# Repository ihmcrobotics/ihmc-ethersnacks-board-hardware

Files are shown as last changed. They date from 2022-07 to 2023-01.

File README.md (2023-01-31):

This repository replicates our internal Circuit Board Design Files repository, but only displays a portion of the material and documentation we intend to make public.
This project is  is licensed under the BSD 3-Clause "New" or "Revised" License.

EtherSNACKS - EtherCAT slave using Texas Instrument F28388 Processor
===
# Overview
EtherSNACKS board is an etherCAT slave based on the F28388D C2000 Real-time microcontroller. It allows any sensors or actuators to be interfaced on EtherCAT using GPIO, ADC, I2C, SPI, UART, CAN...

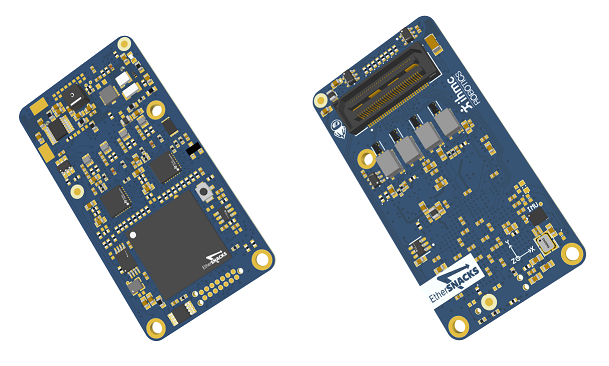
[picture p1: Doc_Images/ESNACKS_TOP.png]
EtherSNACKS Rev 1.2 PCB Top

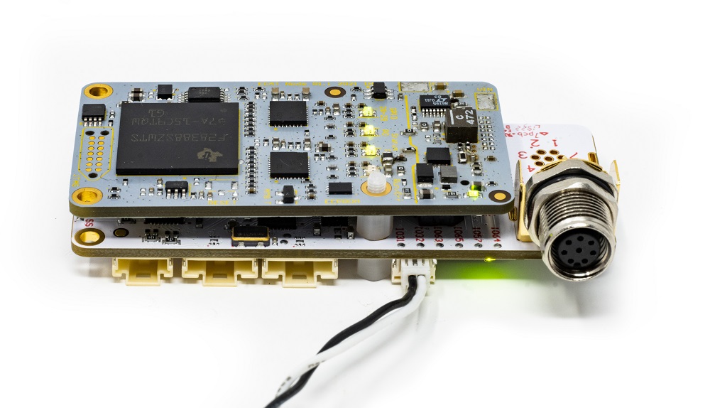
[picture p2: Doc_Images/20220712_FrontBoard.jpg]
EtherSNACKS on a daughter board


### Hardware release (production files)
* Rev 1.0 Initial version 

* Rev 1.1 Released version to fab with 8 layers stackup

* Rev 1.2 Change resistor R77 ADC REF to 100R instead of 1K 
		  Reverse voltage protection diode added

### Features
* TMS320F28388D 200 MHz dual C28xCPUs and dual CLAs, Connectivity Manager (CM) based on the ARM Cortex-M4 processor 125Mhz
* EtherCAT build-in and CAN-FD communication ports(CAN needs an external transceiver)
* IMU 6-axes TDK ICM-42688-P High-Precision with 32,768KHz external clock
* Ambient temperature sensor
* Voltage supervisors (3V3 and 1V2 CPU)
* ADC reference 3V ±0.05%
* 2 programmable LEDs
* Reset button
* JTAG 14-pin Plug-of-Nails (TC2070-IDC-NL)
* Boad-to-board 60 pins connector:
	* 2-port EtherCAT
	* 1-port CAN-FD
	* 2x I2C
	* 8x PWM (4*2 complementary PWM)
	* 3x SPI
	* 8x ADC
	* 2x SCI (UART)
	* up to 39 GPIOs (depending on the config)

### Electrical specifications
* Wide input voltage range: 8V to 60V
* Onboard buck 5V 1.2A
* Onboard buck 3V3 800mA

### Mechanical dimensions
* 58mm x 30.5mm (2.28" X 1.2")
* Height≈7.75mm

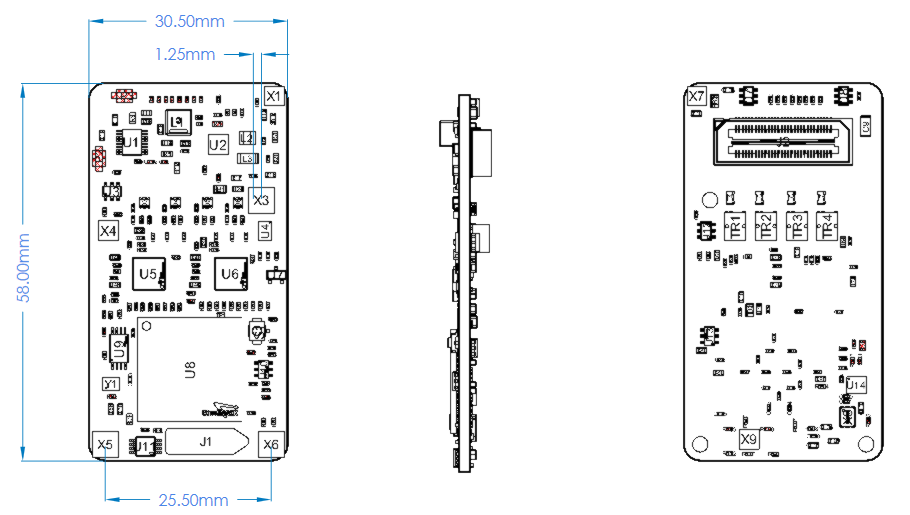
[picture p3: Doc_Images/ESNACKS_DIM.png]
EtherSNACKS Rev 1.2 Dimensions


### Files
Each board has its own folder containing the source files (schematic and layout on Altium), output files (gerber, BOM and pick and place for manufacturing), documents (schematic and layout in PDF files), images, configuration files for etherCAT etc.

### Examples
Onboard TDK ICM-42688P IMU on EtherCAT (TwinCAT):

Onboard TDK ICM-42688P IMU

STIM318 IMU interfaced with EtherSNACKS:

STIM318 IMU interfaced with EtherSNACKS

EtherSNACKS Testbed for development:

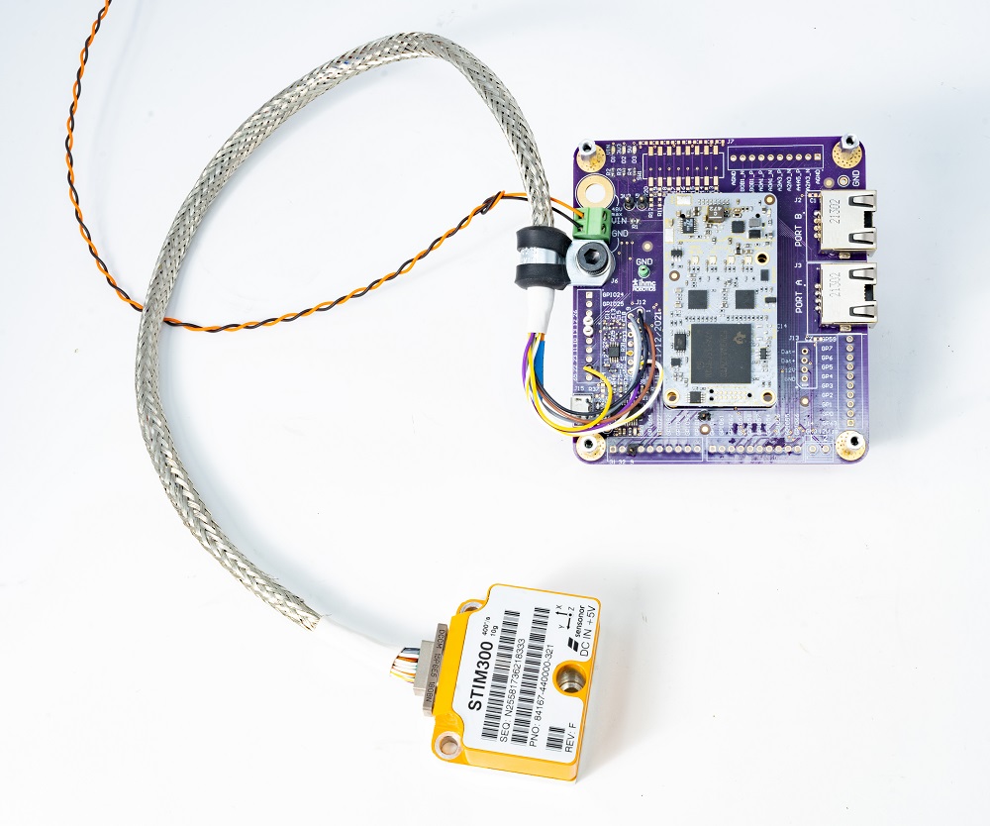
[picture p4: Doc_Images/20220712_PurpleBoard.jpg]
EtherSNACKS Testbed


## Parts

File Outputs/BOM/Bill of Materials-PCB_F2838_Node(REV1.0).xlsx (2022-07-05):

Designator | MPN | Quantity | Description | Footprint | Value
C1, C2, C3, C4, C5, C6, C7, C8 | CC0402JRNPO9BN331 | 8 | 0402 330 pF 50 V ±5 % Tolerance NP0 SMT Multilayer Ceramic Capacitor | 0402_C | 330p
C9 | C3216X7S2A225K160AB | 1 | CAP CER 2.2UF 100V X7S 1206 | CAPC3216X16N(1206) | 2.2uF
C10 | 885012005043 | 1 | Cap, Mlcc, Np0, 33Pf, 25V, 0402 Rohs Compliant: Yes | 0402_C | 33pF
C11, C13, C19, C21, C95, C106 | C1608X5R1A226M080AC | 6 | CAP CER 22UF 10V X5R 0603 | CAPC1608X09N(0603) | 22uF
C12, C14, C17 | CL10B104KC8NNNC | 3 | CAP CER 0.1UF 100V X7R 0603 | CAPC1608X09N(0603) | 0.1uF
C15, C20, C23, C25, C26, C27, C28, C29, C30, C31, C32, C33, C38, C39, C40, C43, C44, C47, C49, C50, C52, C56, C57, C58, C61, C65, C66, C67, C74, C75, C77, C78, C79, C80, C82, C83, C84, C85, C86, C87, C88, C90, C91, C92, C93, C94, C96, C97, C98, C99, C100, C103, C104, C105, C110 | GRM155R71C104JA88D | 55 | CAP CER 0.1UF 16V X7R 0402 | CAPC1005X03N(0402) | 100nF
C16, C18, C36, C37, C42, C46, C54, C55, C59, C60, C64, C73, C109 | C0603C105K3PACTU | 13 | MLCC - SMD/SMT 25volts 1uF X5R 10% | CAPC1608X09N(0603) | 1uF
C24, C89, C102, C107, C108, C111 | GRM188R61A225KE34D | 6 | CAP CER 2.2UF 10V X5R 0603 | CAPC1608X09N(0603) | 2.2uF
C34, C35 | C1005NP01H102J050BA | 2 | CAP CER 1000PF 50V NP0 0402 | 0402_C | 1nF
C41, C45, C63, C68, C72, C76 | CL10X106MO8NRNC | 6 | CAP CER 10UF 16V X6S 0603 | CAPC1608X09N(0603) | 10uF
C48 | GCM1555C1H471JA16D | 1 | CAP CER 470PF 50V C0G/NP0 0402 | CAPC1005X03N(0402) | 470pF
C51, C53, C62, C69, C70, C71, C101 | CC0402KRX7R9BB103 | 7 | CAP CER 10000PF 50V X7R 0402 | CAPC1005X03N(0402) | 10nF
C81 | CL10B104KB8NNNL | 1 | CAP CER 0.1UF 50V X7R 0603 | CAPC1608X09N(0603) | 100nF
D1 | LTST-C193KGKT-5A | 1 | LED GREEN CLEAR CHIP SMD | LEDC1608X07N(0603)
D2 | CFSH05-20L TR | 1 | Silicon SCHOTTKY Diode Low Forward Voltage 20V 3A 2-Pin SOD-882L Surface Mount T/R | SOD-882
D3, D6 | LTST-C195KGJRKT | 2 | LED GREEN/RED CLEAR CHIP SMD | Dual_LED
D4, D5 | LTST-C195KGJSKT | 2 | LED GREEN/YELLOW CLEAR CHIP SMD | Dual_LED
D7, D8 | TPD4E001QDBVRQ1 | 2 | TVS DIODE 5.5V 16V SOT23-6 | FP-DBV0006A-IPC_C
FB1, FB2, FB3 | BKP2125HS600-T | 3 | TAIYO YUDEN - BKP2125HS600-T - Ferrite Bead, 0805 [2012 Metric], 60 ohm, 3 A, BKP Series, 0.025 ohm, ± 25% | FP-BKP2125-IPC_C
J2 | QSH-030-01-F-D-A-K-TR | 1 | Conn Micro High Speed Socket Strip SKT 60 POS 0.5mm Solder ST SMD Automotive T/R | FP-QSH-030-01-F-D-A-K-TR-MFG
L1 | XGL4030-472MEC | 1 | Inductor Power Shielded Wirewound 4.7uH 20% 1MHz Composite 6.6A 31.5mOhm DCR Automotive T/R | FP-XGL4030-472MEC-MFG | 4u7
L2 | 74438323033 | 1 | Inductor Power Shielded Wirewound 3.3uH 20% 100KHz Powdered Iron 1.25A 264mOhm DCR 1008 T/R | SMD 2510 | 3u3
L3 | PFL3215-222MEB | 1 | Power inductor, shielded, 20% tol, SMT, RoHS, halogen-f | 1206_L | 2u2
L4, L5, L6, L7 | DLW21HN900SQ2L | 4 | MURATA - DLW21HN900SQ2L - Filter, Common Mode, 90 ohm, 0.33 A, DLW21H Series, 2 mm x 1.2 mm x 0.9 mm | FP-DLW21HN-MFG
R1 | ERJ-2RKF2003X | 1 | Res Thick Film 0402 200K Ohm 1% 1/10W ±100ppm/|C SMD Punched Carrier T/R | 0402 | 200k
R2 | CRCW0402205KFKED | 1 | Res Thick Film 0402 205K Ohm 1% 1/16W ±100ppm/°C Molded SMD SMD Paper T/R | 0402 | 205k
R3 | RC0603FR-071ML | 1 | RES SMD 1M OHM 1% 1/10W 0603 | RESC1608X09N(0603) | 1M
R4 | CRCW040222K0JNED | 1 | Res Thick Film 0402 22K Ohm 5% 1/16W ±200ppm/°C Molded SMD SMD Paper T/R | 0402 | 22k
R5 | ERJ-3EKF1003V | 1 | Res Thick Film 0603 100K Ohm 1% 0.1W(1/10W) ±100ppm/C Pad SMD Automotive T/R | RESC1608X09N(0603) | 100k
R6, R37, R38, R78, R99, R109, R110 | RC0402FR-0710KL | 7 | RES SMD 10K OHM 1% 1/16W 0402 | RESC1005X06N(0402) | 10k
R7 | RC0603FR-07680RL | 1 | RES SMD 680 OHM 1% 1/10W 0603 | RESC1608X09N(0603) | 680R
R8, R12, R17 | RC0603JR-070RL | 3 | RES SMD 0 OHM JUMPER 1/10W 0603 | RESC1608X09N(0603) | 0R
R9 | CRCW0402340KFKED | 1 | Res Thick Film 0402 340K Ohm 1% 1/16W ±100ppm/°C Molded SMD SMD Paper T/R | 0402 | 340k
R10 | ERJ-2RKF2002X | 1 | RES SMD 20K OHM 1% 1/10W 0402 | 0402 | 20k
R13, R43, R44, R45, R47, R71, R75, R76, R81, R82, R83, R84, R85, R86, R87, R88, R102, R103, R105, R111 | RCS04020000Z0ED | 20 | VISHAY - RCS04020000Z0ED - SMD Chip Resistor, 0402 [1005 Metric], 0 ohm, RCS Series, 50 V, Thick Film, 200 mW | 0402 | 0R
R14, R18, R89, R90 | CRCW04021M50JNED | 4 | RES SMD 1.5M OHM 5% 1/16W 0402 | 0402 | 1M5
R15 | RT0603DRE0775KL | 1 | Res Thin Film 0603 75K Ohm 0.5% 1/10W ±50ppm/°C Molded SMD SMD Paper T/R | 0603 | 75k
R16 | RC0402FR-072KL | 1 | RES SMD 2K OHM 1% 1/16W 0402 | RESC1005X06N(0402) | 2k
R19, R20, R21, R22, R23, R24, R25, R26 | CRCW0402470RJNED | 8 | Vishay CRCW Series Thick Film Resistor 0402 Case 470 5% 0.063W 200ppm/K | 0402 | 470
R27, R28, R29, R30 | CRCW040275R0FKEDC | 4 | RES SMD 75 OHM 1% 1/16W 0402 | RESC1005X06N(0402) | 75R
R31, R32, R33, R34, R92, R93, R94, R96, R107 | CRCW040249R9FKED | 9 | RES SMD 49.9 OHM 1% 1/16W 0402 | RESC1005X06N(0402) | 49.9
R35, R36, R112, R113 | RC0402FR-074K75L | 4 | RES SMD 4.75K OHM 1% 1/16W 0402 | RESC1005X06N(0402) | 4k75
R39, R40, R41, R42, R49, R50, R51, R52, R53, R54, R55, R56, R57, R58, R59, R60, R61, R62, R63, R64, R69, R72, R73, R74, R100, R101, R106 | CRCW04022K20JNED | 27 | Vishay CRCW Series Thick Film Resistor 0402 Case 2.2k 5% 0.063W 200ppm/K | 0402 | 2k2
R46, R48 | CRCW04022K49FKED | 2 | VISHAY - CRCW04022K49FKED - Chipwiderstand, Oberflächenmontage, Dickschicht, 0402 [Metrisch 1005], 2.49 kohm, Baureihe CRCW | 0402 | 2K49
R65 | CRCW0402220RFKED | 1 | RES SMD 220 OHM 1% 1/16W 0402 | RESC1005X06N(0402) | 220
R66, R67, R68 | ERA-2AKD100X | 3 | Res Thin Film 0402 10 Ohm 0.5% 1/16W 100ppm/C Molded SMD SMD Punched Carrier T/R | 0402 | 10
R77 | CRCW06031K00FKEA | 1 | MD 1/10watt 1.0Kohms 1% | RESC1608X09N(0603) | 1k
R79, R80 | CRCW040256K0JNED | 2 | Res Thick Film 0402 56K Ohm 5% 0.063W(1/16W) ±200ppm/C Pad SMD Automotive T/R | 0402 | 56K
R91, R95 | CRCW04024K87FKED | 2 | Res Thick Film 0402 4.87K Ohm 1% 1/16W 100ppm/C Molded SMD SMD Paper T/R | 0402 | 4k87
R97 | CRCW040256R0JNED | 1 | RES SMD 56 OHM 5% 1/16W 0402 | 0402 | 56
R98 | CRCW060310K0FKEAHP | 1 | RES SMD 10K OHM 1% 1/4W 0603 | RESC1608X09N(0603) | 10k
R104, R108 | ERJ2BWFR100X_RES | 2 | RES 0.1 OHM 1% 1/4W 0402 | 0402 | 0.1
S1 | B3U-1100P | 1 | Switch Tactile N.O. SPST Round Button Gull Wing 0.05A 12VDC 1.5N SMD Embossed T/R | FP-B3U-1100P-MFSWITCH_G
S2 | 218-2LPST | 1 | Switch DIP ON OFF SPST 2 Recessed Slide 0.025A 24VDC Gull Wing 1000Cycles 1.27mm SMD Tube | CTS-218-2LPST_V
TR1, TR2, TR3, TR4 | ALT4532M-201-T001 | 4 | Telecom Transformer 1CT:1CT 6 Terminal SMD | ALT4532M_LAN_Transformer
U1 | LT8619IMSE-5#PBF | 1 | LT8619 - 60V, 1.2A Synchronous Monolithic Buck Regulator with 6µA Quiescent Current | SOP50P490X110-17N
U2 | TPS62410DRCR | 1 | TPS62410 2.25MHZ 2X800MA Dual St | DRC0010J_V - 3vias
U3 | SN74LVC2G07DBVR | 1 | Buffer/Driver 2-CH Non-Inverting Open Drain CMOS 6-Pin SOT-23 T/R | DBV0006A_M
U4 | CAT24C16HU4I-GT3 | 1 | EEPROM Serial-2Wire 16K-bit 2K x 8 1.8V/2.5V/3.3V/5V Automotive 8-Pin UDFN EP T/R | UDFN8-EP
U5, U6 | DP83822IRHBR | 2 | IC TXRX ETHERNET 32VQFN | FP-RHB0032B-MFG
U7 | TMP236AQDBZTQ1 | 1 | TMP23x-Q1 Automotive Grade, High-Accuracy Analog Output Temperature Sensors | SOT23
U8 | F28388DZWTS | 1 | 32-bit MCU with connectivity manager, 2x C28x+CLA CPU, 1.5 MB flash, FPU64, CLB, Ethernet, EtherCAT 337-NFBGA -40 to +125 | FP-ZWT0337A-IPC_B - ESNACK
U9 | CDCLVC1104PW | 1 | Clock Fanout Buffer 4-OUT 8-Pin TSSOP Tube | FP-PW0008A-IPC_B
U10 | TPS3702CX33DDCT | 1 | Processor Supervisor 3.3V 1 Active Low/Open Drain 6-Pin TSOT-23 T/R | FP-DDC0006A-IPC_A
U11 | REF5030IDGKT | 1 | IC VREF SERIES 3V 8VSSOP | DGK0008A_L
U12 | SN74LVC2G06DBVR | 1 | Buffer/Driver 2-CH Inverting Open Drain CMOS 6-Pin SOT-23 T/R | FP-DBV0006A-IPC_C
U13 | TPS3702CX12DDCT | 1 | Processor Supervisor 1.2V 1 Active Low/Open Drain 6-Pin TSOT-23 T/R | FP-DDC0006A-IPC_A
U14 | ICM-42688-P | 1 | Accelerometer and Gyroscope 6-Axis MEMS Motion Tracking Device Digital-OUT 14-Pin LGA T/R | PQFN50P300X250X97-14N
X8 | 32.768Khz_OSC_KX3211A0032.768000 | 1 | SMD Crystal Oscillator 0.032768MHz 3.3V 15pF 4-Pin CSMD | KX3211A0032.768000
Y1 | ECS-2520S33-250-FN-TR | 1 | Oscillator XO 25MHz ±10ppm 15pF HCMOS 55% 3.3V 4-Pin Mini-CSMD T/R | XTAL_ECS-2520S

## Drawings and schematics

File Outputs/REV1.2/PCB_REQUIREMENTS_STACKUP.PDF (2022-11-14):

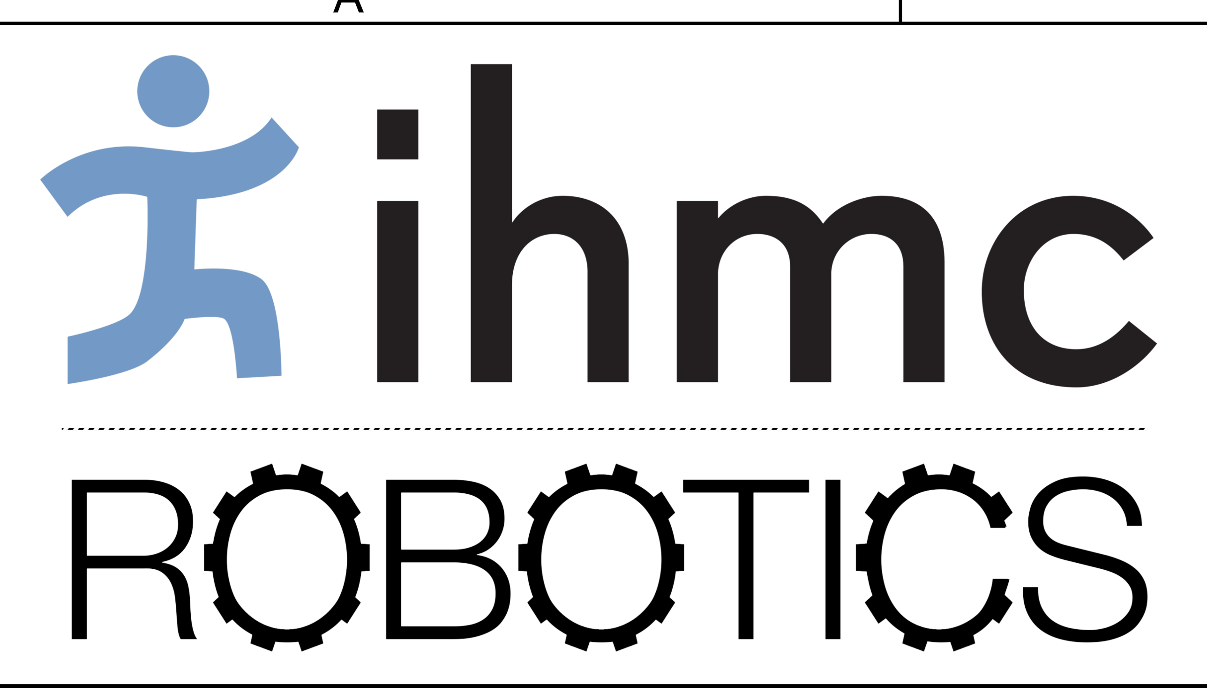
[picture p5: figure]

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
1 | 1
2 | 2
3 | 3
4 | 4

# PCB Requierements

REV DOC:

PCB:

DESIGNED: | DATE:
11/14/2022 | SHEET 1 | OF 2

CONFIDENTIAL
© IHMC inc. , 2020

A

11/14/2022

PCB_F2838_Node.PcbDoc

Alexis
Maslyczyk

## 1. Compliance to standards

- Printed circuit board shall be manufactured as per IPC-6012 Class 2.
- Printed circuit board shall be RoHS compliant.
- Printed circuit board shall be UL796 compliant.
- Printed circuit board shall meet UL94 V-0 flammability rating.
- The acceptability of the printed circuit boards shall be evaluated according to IPC-A-600 Class 2.
- Board dimensions shall be as specified in the drill drawing Gerber file.
- Board dimensions are in mms. Tolerances are .XXX +/- 0.127mm

## 2. Board dimensions / tolerances

## 3. Silkscreen

- Silkscreen shall be non-conductive epoxy ink.
- Silkscreen shall be applied on top of soldermask.
- Silkscreen clearance with solderable copper patterns shall be of at least 0.005’’ (5 mil).
- Silkscreen shall be applied using a process that ensures that all printed characters are legible.
- Silkscreen clipping is permitted to achieve design and process requirements
- Silkscreen shall be applied using common thermal curing process to print the slikscreen text.
- Silkscreen shall withstand reflow and normal cleaning process.

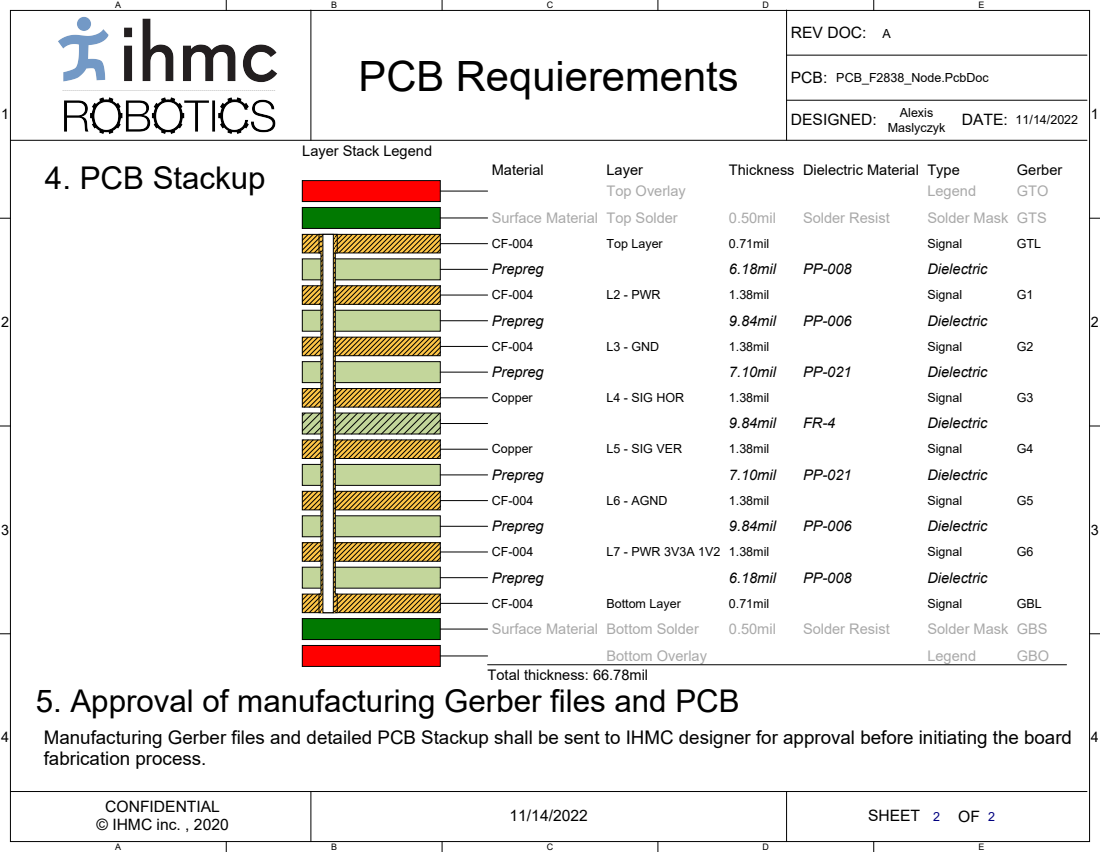
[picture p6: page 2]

5. Approval of manufacturing Gerber files and PCB

Manufacturing Gerber files and detailed PCB Stackup shall be sent to IHMC designer for approval before initiating the board
fabrication process.

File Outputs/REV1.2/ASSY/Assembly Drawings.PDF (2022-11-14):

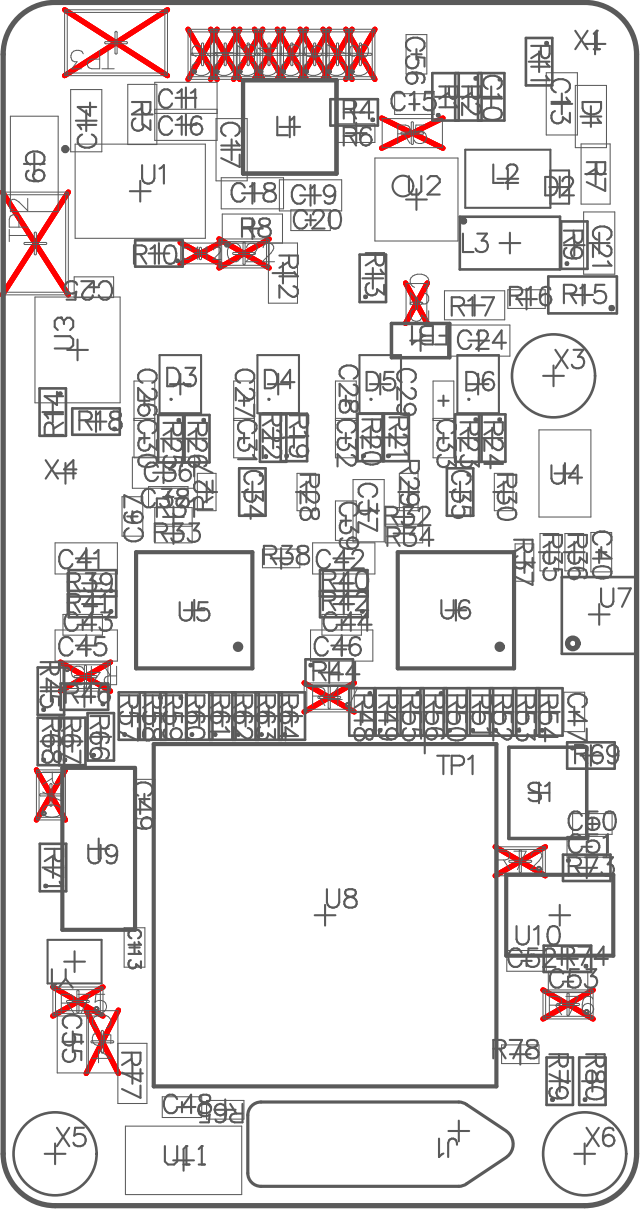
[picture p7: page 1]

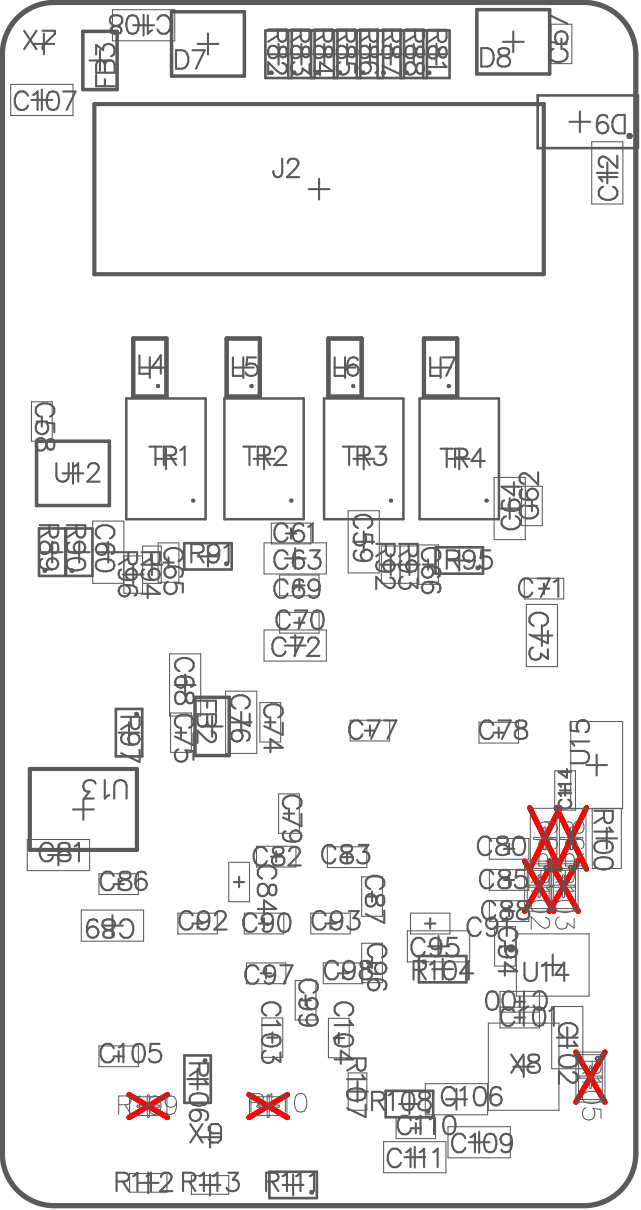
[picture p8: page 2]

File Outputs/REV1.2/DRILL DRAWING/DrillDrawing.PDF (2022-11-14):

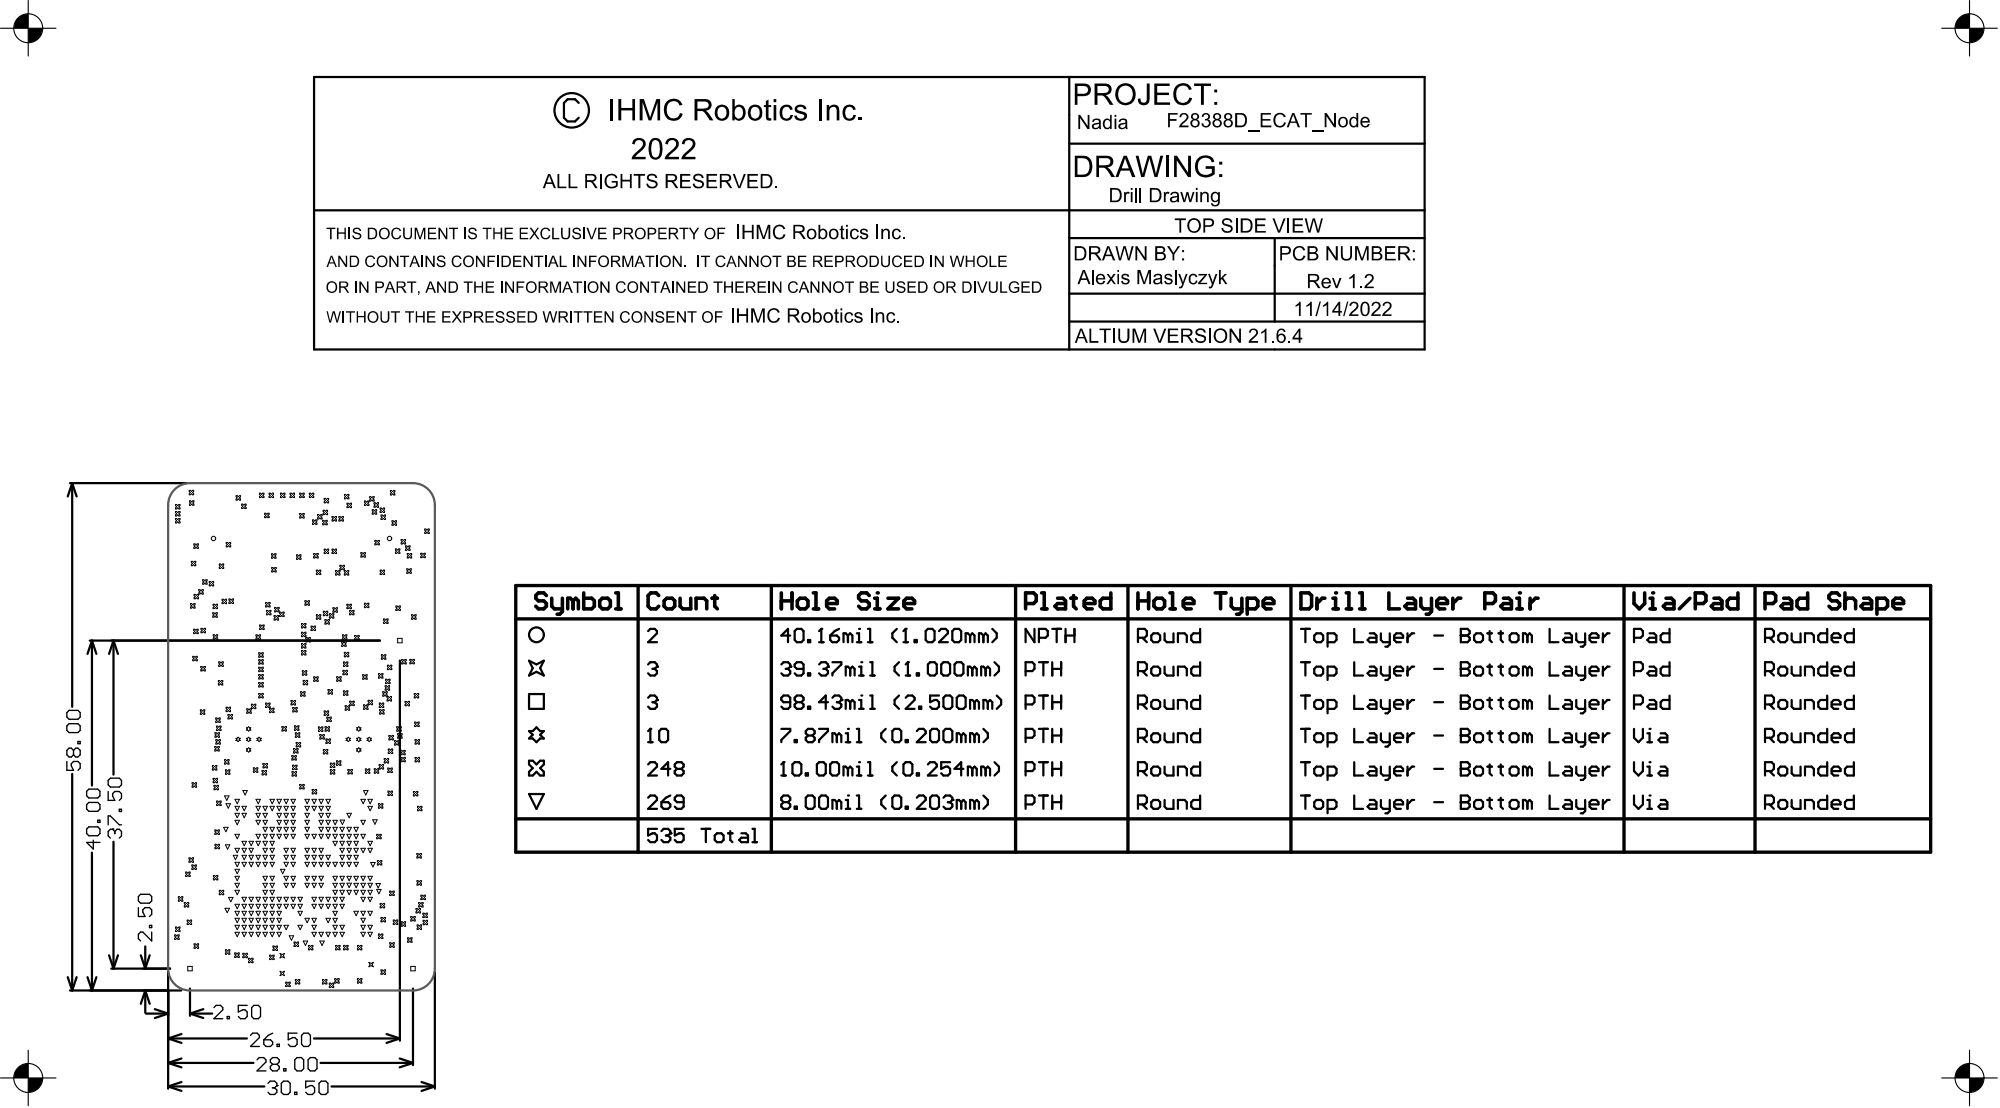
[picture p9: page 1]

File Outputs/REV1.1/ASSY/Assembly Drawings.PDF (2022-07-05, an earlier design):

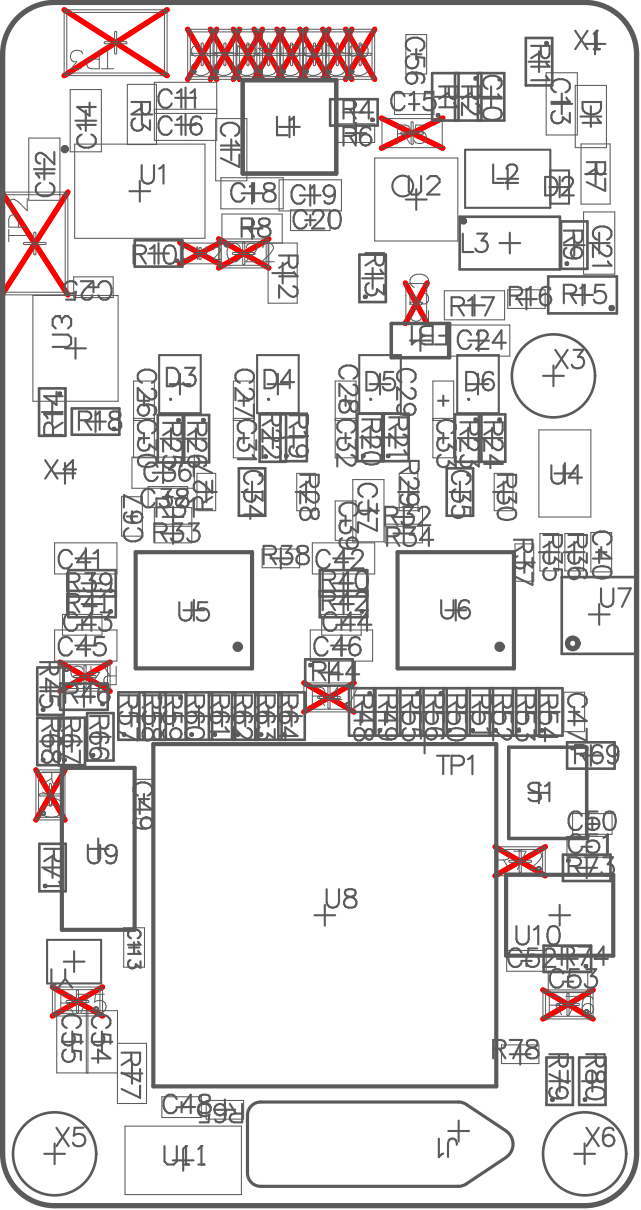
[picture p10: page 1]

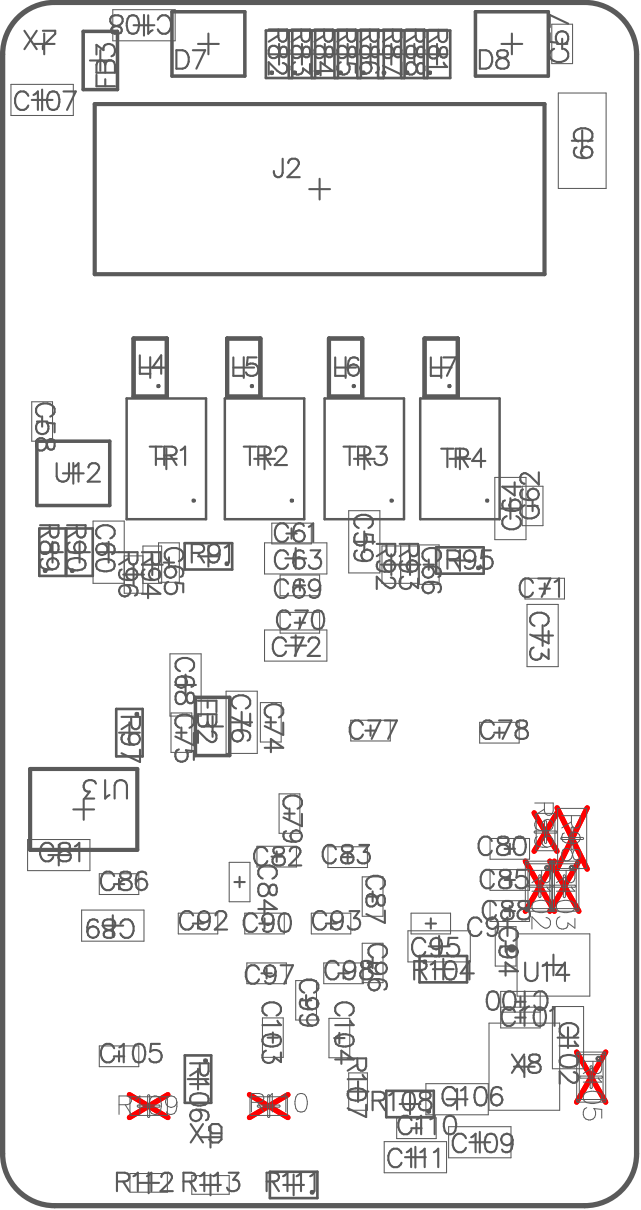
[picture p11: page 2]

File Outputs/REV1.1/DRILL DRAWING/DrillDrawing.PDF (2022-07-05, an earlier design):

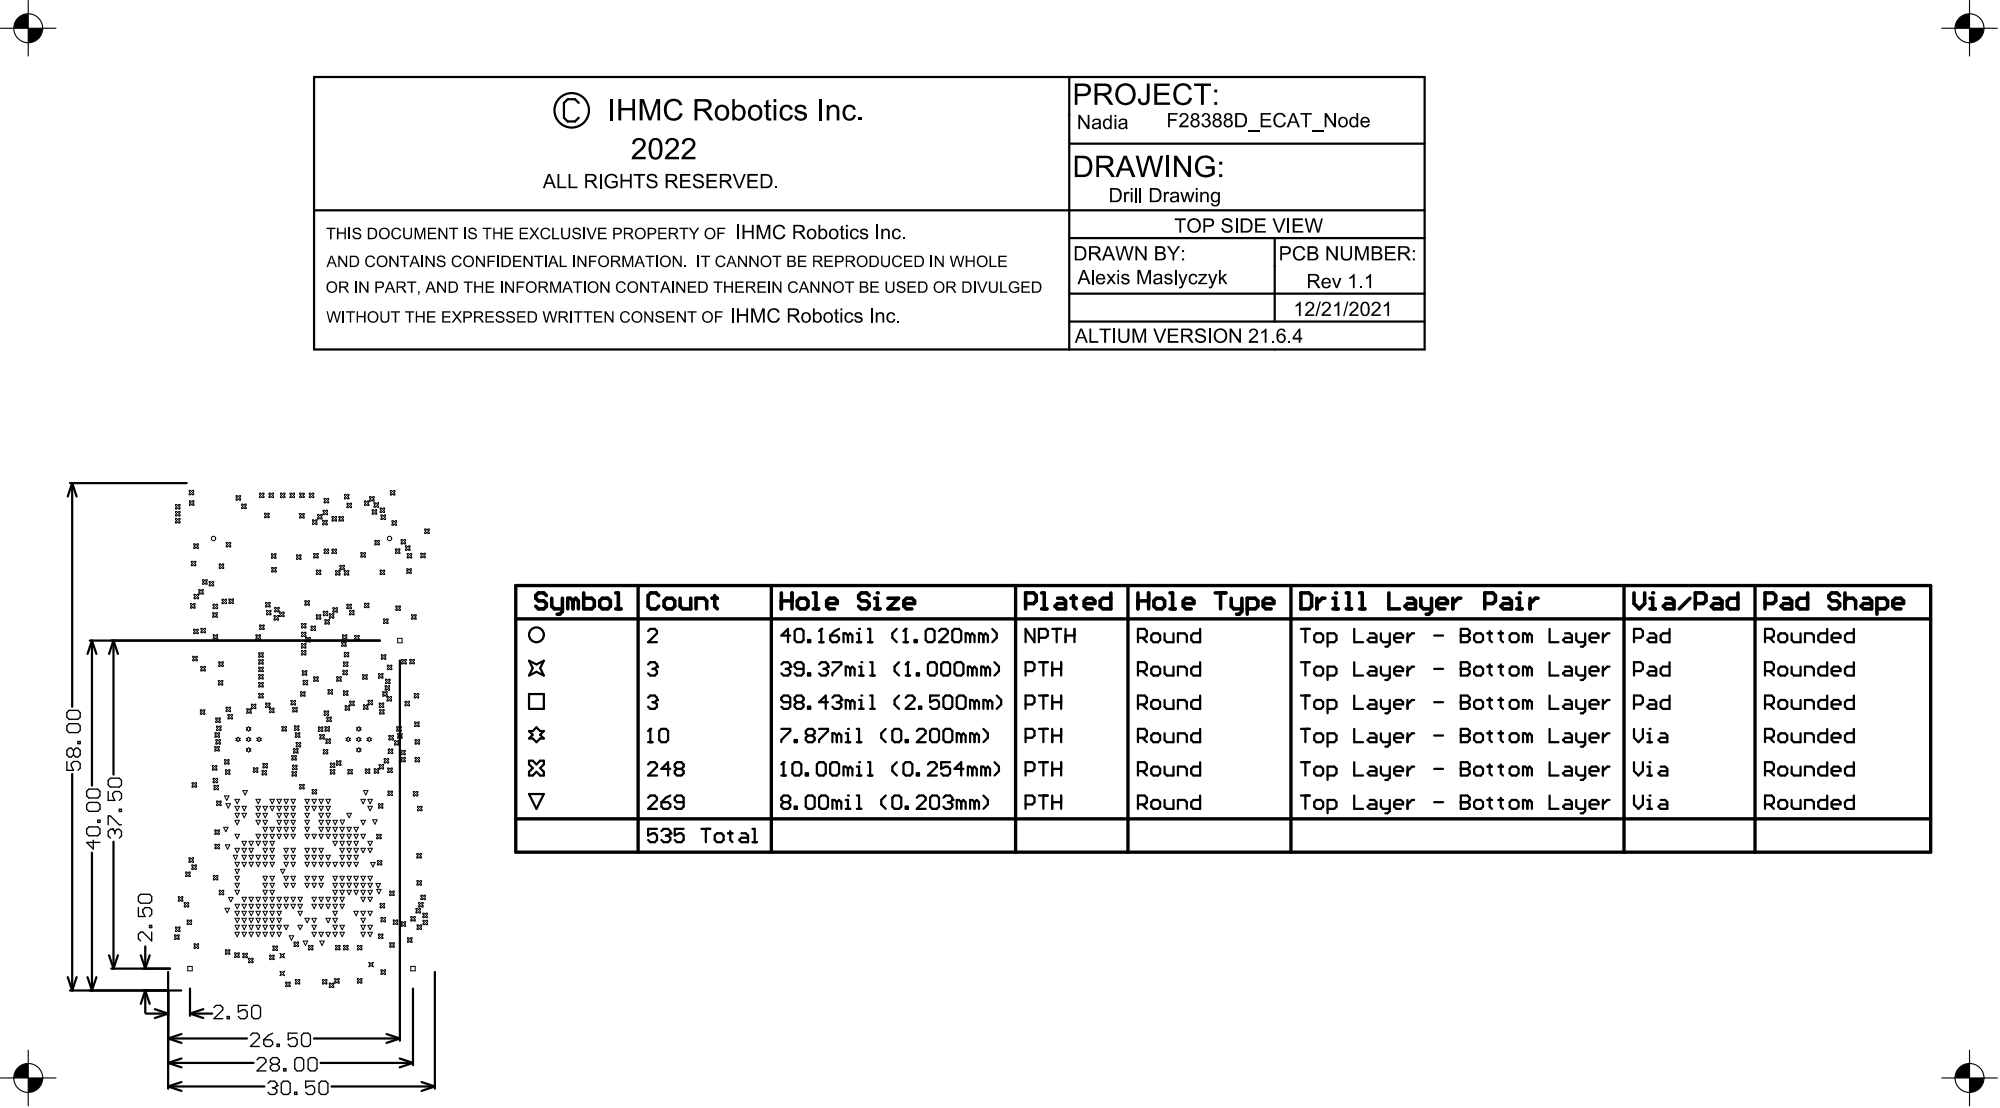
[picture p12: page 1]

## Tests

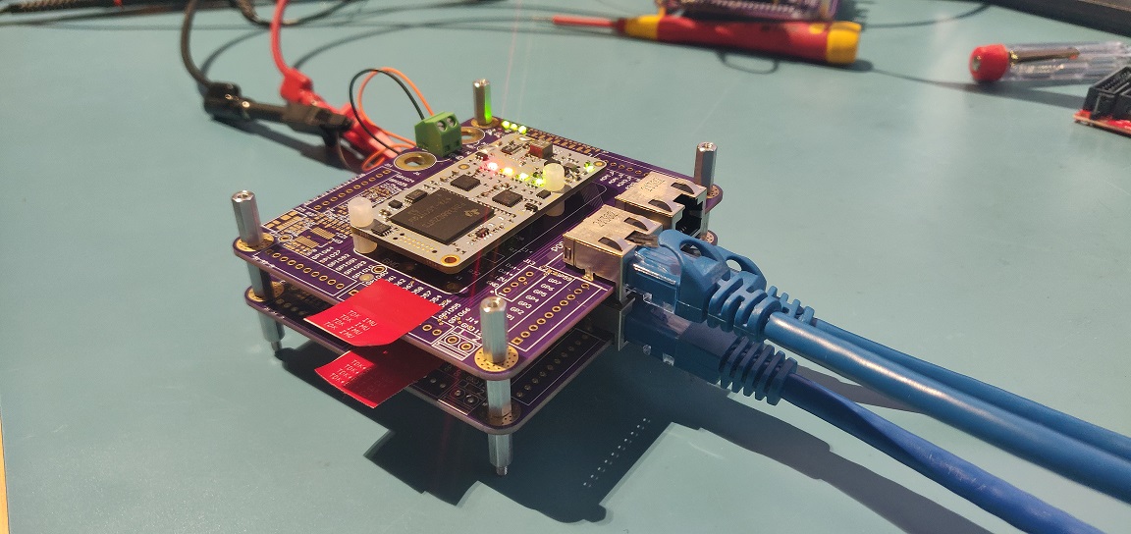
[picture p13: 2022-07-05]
Doc_Images/TESTBED.jpg

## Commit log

2022-11-14 Added schottky diode for reverse pol
    [[8] CONNECTORS MECH.SchDoc]
2022-11-14 Release Rev 1.2 -ADC ref fixed with 0R -Onboard EEPROM added -Diode for polarity protection added
    [Bill of Materials-PCB_F2838_Node(REV1.2).xlsx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]
2023-01-30 License added
    [PCB_F2838_Node.PrjPcb]
2023-11-16 Changes: 3d model of the clock (bug with onshape)
    [PCB_F2838_Node.PrjPcb, [4] F2838 JTAG CLOCK SUP.SchDoc]
